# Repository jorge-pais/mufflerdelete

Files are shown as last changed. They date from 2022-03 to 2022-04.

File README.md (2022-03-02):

# Muffler Delete
Guitar distortion/fuzz effect based on the 72' Triangle Big Muff, featuring an alternate clipping mode using LEDs and a seperate boost circuit.

## Circuit Schematic
surface11700

## 3D Board View
muffboard
muffboard

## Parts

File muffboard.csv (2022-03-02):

Source: | /home/jorge/repos/muffboard/muffboard.kicad_sch
Date: | qua 02 mar 2022 12:33:31
Tool: | Eeschema (6.0.2)
Generator: | /usr/share/kicad/plugins/bom_csv_grouped_by_value.py
Component Count: | 65
Individual Components:
Item | Qty | Reference(s) | Value | LibPart | Footprint | Datasheet
 |  | C1 | 100n | Device:C | Capacitor_THT:C_Rect_L7.2mm_W2.5mm_P5.00mm_FKS2_FKP2_MKS2_MKP2 | ~
 |  | C2 | 100u | Device:C_Polarized | Capacitor_THT:CP_Radial_D6.3mm_P2.50mm | ~
 |  | C3 | 470p | Device:C | Capacitor_THT:C_Rect_L7.2mm_W2.5mm_P5.00mm_FKS2_FKP2_MKS2_MKP2 | ~
 |  | C4 | 100n | Device:C | Capacitor_THT:C_Rect_L7.2mm_W2.5mm_P5.00mm_FKS2_FKP2_MKS2_MKP2 | ~
 |  | C5 | 100n | Device:C | Capacitor_THT:C_Rect_L7.2mm_W2.5mm_P5.00mm_FKS2_FKP2_MKS2_MKP2 | ~
 |  | C6 | 47n | Device:C | Capacitor_THT:C_Rect_L7.2mm_W2.5mm_P5.00mm_FKS2_FKP2_MKS2_MKP2 | ~
 |  | C7 | 470p | Device:C | Capacitor_THT:C_Rect_L7.2mm_W2.5mm_P5.00mm_FKS2_FKP2_MKS2_MKP2 | ~
 |  | C8 | 100n | Device:C | Capacitor_THT:C_Rect_L7.2mm_W2.5mm_P5.00mm_FKS2_FKP2_MKS2_MKP2 | ~
 |  | C9 | 47n | Device:C | Capacitor_THT:C_Rect_L7.2mm_W2.5mm_P5.00mm_FKS2_FKP2_MKS2_MKP2 | ~
 |  | C10 | 470p | Device:C | Capacitor_THT:C_Rect_L7.2mm_W2.5mm_P5.00mm_FKS2_FKP2_MKS2_MKP2 | ~
 |  | C11 | 4n | Device:C | Capacitor_THT:C_Rect_L7.2mm_W2.5mm_P5.00mm_FKS2_FKP2_MKS2_MKP2 | ~
 |  | C12 | 10n | Device:C | Capacitor_THT:C_Rect_L7.2mm_W2.5mm_P5.00mm_FKS2_FKP2_MKS2_MKP2 | ~
 |  | C13 | 100n | Device:C | Capacitor_THT:C_Rect_L7.2mm_W2.5mm_P5.00mm_FKS2_FKP2_MKS2_MKP2 | ~
 |  | C14 | 100n | Device:C | Capacitor_THT:C_Rect_L7.2mm_W2.5mm_P5.00mm_FKS2_FKP2_MKS2_MKP2 | ~
 |  | C15 | 100n | Device:C | Capacitor_THT:C_Rect_L7.2mm_W2.5mm_P5.00mm_FKS2_FKP2_MKS2_MKP2 | ~
 |  | C16 | 100n | Device:C | Capacitor_THT:C_Rect_L7.2mm_W2.5mm_P5.00mm_FKS2_FKP2_MKS2_MKP2 | ~
 |  | D1 | 1N4007 | Diode:1N4007 | Diode_THT:D_DO-41_SOD81_P10.16mm_Horizontal | http://www.vishay.com/docs/88503/1n4001.pdf
 |  | D2 | 1N4148 | Diode:1N4148 | Diode_THT:D_DO-35_SOD27_P7.62mm_Horizontal | https://assets.nexperia.com/documents/data-sheet/1N4148_1N4448.pdf
 |  | D3 | 1N4148 | Diode:1N4148 | Diode_THT:D_DO-35_SOD27_P7.62mm_Horizontal | https://assets.nexperia.com/documents/data-sheet/1N4148_1N4448.pdf
 |  | D4 | RED | Device:LED | LED_THT:LED_D3.0mm | ~
 |  | D5 | RED | Device:LED | LED_THT:LED_D3.0mm | ~
 |  | D6 | 1N4148 | Diode:1N4148 | Diode_THT:D_DO-35_SOD27_P7.62mm_Horizontal | https://assets.nexperia.com/documents/data-sheet/1N4148_1N4448.pdf
 |  | D7 | 1N4148 | Diode:1N4148 | Diode_THT:D_DO-35_SOD27_P7.62mm_Horizontal | https://assets.nexperia.com/documents/data-sheet/1N4148_1N4448.pdf
 |  | D8 | RED | Device:LED | LED_THT:LED_D3.0mm | ~
 |  | D9 | RED | Device:LED | LED_THT:LED_D3.0mm | ~
 |  | J1 | Conn_01x02 | Connector_Generic:Conn_01x02 | Connector_PinHeader_2.54mm:PinHeader_1x02_P2.54mm_Vertical | ~
 |  | J2 | Conn_01x03 | Connector_Generic:Conn_01x03 | Connector_PinHeader_2.54mm:PinHeader_1x03_P2.54mm_Vertical | ~
 |  | J3 | Conn_01x03 | Connector_Generic:Conn_01x03 | Connector_PinHeader_2.54mm:PinHeader_1x03_P2.54mm_Vertical | ~
 |  | Q1 | BC547 | Transistor_BJT:BC547 | Package_TO_SOT_THT:TO-92_Inline_Wide | https://www.onsemi.com/pub/Collateral/BC550-D.pdf
 |  | Q2 | BC547 | Transistor_BJT:BC547 | Package_TO_SOT_THT:TO-92_Inline_Wide | https://www.onsemi.com/pub/Collateral/BC550-D.pdf
 |  | Q3 | BC547 | Transistor_BJT:BC547 | Package_TO_SOT_THT:TO-92_Inline_Wide | https://www.onsemi.com/pub/Collateral/BC550-D.pdf
 |  | Q4 | BC547 | Transistor_BJT:BC547 | Package_TO_SOT_THT:TO-92_Inline_Wide | https://www.onsemi.com/pub/Collateral/BC550-D.pdf
 |  | Q5 | BC547 | Transistor_BJT:BC547 | Package_TO_SOT_THT:TO-92_Inline_Wide | https://www.onsemi.com/pub/Collateral/BC550-D.pdf
 |  | R1 | 1M | Device:R | Resistor_THT:R_Axial_DIN0207_L6.3mm_D2.5mm_P7.62mm_Horizontal | ~
 |  | R2 | 33k | Device:R | Resistor_THT:R_Axial_DIN0207_L6.3mm_D2.5mm_P7.62mm_Horizontal | ~
 |  | R3 | 100k | Device:R | Resistor_THT:R_Axial_DIN0207_L6.3mm_D2.5mm_P7.62mm_Horizontal | ~
 |  | R4 | 470k | Device:R | Resistor_THT:R_Axial_DIN0207_L6.3mm_D2.5mm_P7.62mm_Horizontal | ~
 |  | R5 | 15k | Device:R | Resistor_THT:R_Axial_DIN0207_L6.3mm_D2.5mm_P7.62mm_Horizontal | ~
 |  | R6 | 150 | Device:R | Resistor_THT:R_Axial_DIN0207_L6.3mm_D2.5mm_P7.62mm_Horizontal | ~
 |  | R7 | 1k | Device:R | Resistor_THT:R_Axial_DIN0207_L6.3mm_D2.5mm_P7.62mm_Horizontal | ~
 |  | R8 | 8.2k | Device:R | Resistor_THT:R_Axial_DIN0207_L6.3mm_D2.5mm_P7.62mm_Horizontal | ~
 |  | R9 | 100k | Device:R | Resistor_THT:R_Axial_DIN0207_L6.3mm_D2.5mm_P7.62mm_Horizontal | ~
 |  | R10 | 470k | Device:R | Resistor_THT:R_Axial_DIN0207_L6.3mm_D2.5mm_P7.62mm_Horizontal | ~
 |  | R11 | 12k | Device:R | Resistor_THT:R_Axial_DIN0207_L6.3mm_D2.5mm_P7.62mm_Horizontal | ~
 |  | R12 | 150 | Device:R | Resistor_THT:R_Axial_DIN0207_L6.3mm_D2.5mm_P7.62mm_Horizontal | ~
 |  | R13 | 8.2k | Device:R | Resistor_THT:R_Axial_DIN0207_L6.3mm_D2.5mm_P7.62mm_Horizontal | ~
 |  | R14 | 100k | Device:R | Resistor_THT:R_Axial_DIN0207_L6.3mm_D2.5mm_P7.62mm_Horizontal | ~
 |  | R15 | 470k | Device:R | Resistor_THT:R_Axial_DIN0207_L6.3mm_D2.5mm_P7.62mm_Horizontal | ~
 |  | R16 | 12k | Device:R | Resistor_THT:R_Axial_DIN0207_L6.3mm_D2.5mm_P7.62mm_Horizontal | ~
 |  | R17 | 150 | Device:R | Resistor_THT:R_Axial_DIN0207_L6.3mm_D2.5mm_P7.62mm_Horizontal | ~
 |  | R18 | 33k | Device:R | Resistor_THT:R_Axial_DIN0207_L6.3mm_D2.5mm_P7.62mm_Horizontal | ~
 |  | R19 | 33k | Device:R | Resistor_THT:R_Axial_DIN0207_L6.3mm_D2.5mm_P7.62mm_Horizontal | ~
 |  | R20 | 470k | Device:R | Resistor_THT:R_Axial_DIN0207_L6.3mm_D2.5mm_P7.62mm_Horizontal | ~
 |  | R21 | 47k | Device:R | Resistor_THT:R_Axial_DIN0207_L6.3mm_D2.5mm_P7.62mm_Horizontal | ~
 |  | R22 | 10k | Device:R | Resistor_THT:R_Axial_DIN0207_L6.3mm_D2.5mm_P7.62mm_Horizontal | ~
 |  | R23 | 390 | Device:R | Resistor_THT:R_Axial_DIN0207_L6.3mm_D2.5mm_P7.62mm_Horizontal | ~
 |  | R24 | 470k | Device:R | Resistor_THT:R_Axial_DIN0207_L6.3mm_D2.5mm_P7.62mm_Horizontal | ~
 |  | R25 | 100k | Device:R | Resistor_THT:R_Axial_DIN0207_L6.3mm_D2.5mm_P7.62mm_Horizontal | ~
 |  | R26 | 12k | Device:R | Resistor_THT:R_Axial_DIN0207_L6.3mm_D2.5mm_P7.62mm_Horizontal | ~
 |  | R27 | 2.7k | Device:R | Resistor_THT:R_Axial_DIN0207_L6.3mm_D2.5mm_P7.62mm_Horizontal | ~
 |  | RV1 | 100k | Device:R_Potentiometer | Potentiometer_THT:Potentiometer_Omeg_PC16BU_Vertical | ~
 |  | RV2 | 100k | Device:R_Potentiometer | Potentiometer_THT:Potentiometer_Omeg_PC16BU_Vertical | ~
 |  | RV3 | 100k | Device:R_Potentiometer | Potentiometer_THT:Potentiometer_Omeg_PC16BU_Vertical | ~
 |  | RV4 | 100k | Device:R_Potentiometer | Potentiometer_THT:Potentiometer_Omeg_PC16BU_Vertical | ~
 |  | SW1 | SW_DPDT_x2 | Switch:SW_DPDT_x2 | Button_Switch_THT:SW_E-Switch_EG1271_DPDT | ~
Collated Components:
Item | Qty | Reference(s) | Value | LibPart | Footprint | Datasheet
1 | 8 | C1, C4, C5, C8, C13, C14, C15, C16 | 100n | Device:C | Capacitor_THT:C_Rect_L7.2mm_W2.5mm_P5.00mm_FKS2_FKP2_MKS2_MKP2 | ~
2 | 1 | C2 | 100u | Device:C_Polarized | Capacitor_THT:CP_Radial_D6.3mm_P2.50mm | ~
3 | 3 | C3, C7, C10 | 470p | Device:C | Capacitor_THT:C_Rect_L7.2mm_W2.5mm_P5.00mm_FKS2_FKP2_MKS2_MKP2 | ~
4 | 2 | C6, C9 | 47n | Device:C | Capacitor_THT:C_Rect_L7.2mm_W2.5mm_P5.00mm_FKS2_FKP2_MKS2_MKP2 | ~
5 | 1 | C11 | 4n | Device:C | Capacitor_THT:C_Rect_L7.2mm_W2.5mm_P5.00mm_FKS2_FKP2_MKS2_MKP2 | ~
6 | 1 | C12 | 10n | Device:C | Capacitor_THT:C_Rect_L7.2mm_W2.5mm_P5.00mm_FKS2_FKP2_MKS2_MKP2 | ~
7 | 1 | D1 | 1N4007 | Diode:1N4007 | Diode_THT:D_DO-41_SOD81_P10.16mm_Horizontal | http://www.vishay.com/docs/88503/1n4001.pdf
8 | 4 | D2, D3, D6, D7 | 1N4148 | Diode:1N4148 | Diode_THT:D_DO-35_SOD27_P7.62mm_Horizontal | https://assets.nexperia.com/documents/data-sheet/1N4148_1N4448.pdf
9 | 4 | D4, D5, D8, D9 | RED | Device:LED | LED_THT:LED_D3.0mm | ~
10 | 1 | J1 | Conn_01x02 | Connector_Generic:Conn_01x02 | Connector_PinHeader_2.54mm:PinHeader_1x02_P2.54mm_Vertical | ~
11 | 2 | J2, J3 | Conn_01x03 | Connector_Generic:Conn_01x03 | Connector_PinHeader_2.54mm:PinHeader_1x03_P2.54mm_Vertical | ~
12 | 5 | Q1, Q2, Q3, Q4, Q5 | BC547 | Transistor_BJT:BC547 | Package_TO_SOT_THT:TO-92_Inline_Wide | https://www.onsemi.com/pub/Collateral/BC550-D.pdf
13 | 1 | R1 | 1M | Device:R | Resistor_THT:R_Axial_DIN0207_L6.3mm_D2.5mm_P7.62mm_Horizontal | ~
14 | 3 | R2, R18, R19 | 33k | Device:R | Resistor_THT:R_Axial_DIN0207_L6.3mm_D2.5mm_P7.62mm_Horizontal | ~
15 | 4 | R3, R9, R14, R25 | 100k | Device:R | Resistor_THT:R_Axial_DIN0207_L6.3mm_D2.5mm_P7.62mm_Horizontal | ~
16 | 5 | R4, R10, R15, R20, R24 | 470k | Device:R | Resistor_THT:R_Axial_DIN0207_L6.3mm_D2.5mm_P7.62mm_Horizontal | ~
17 | 1 | R5 | 15k | Device:R | Resistor_THT:R_Axial_DIN0207_L6.3mm_D2.5mm_P7.62mm_Horizontal | ~
18 | 3 | R6, R12, R17 | 150 | Device:R | Resistor_THT:R_Axial_DIN0207_L6.3mm_D2.5mm_P7.62mm_Horizontal | ~
19 | 1 | R7 | 1k | Device:R | Resistor_THT:R_Axial_DIN0207_L6.3mm_D2.5mm_P7.62mm_Horizontal | ~
20 | 2 | R8, R13 | 8.2k | Device:R | Resistor_THT:R_Axial_DIN0207_L6.3mm_D2.5mm_P7.62mm_Horizontal | ~
21 | 3 | R11, R16, R26 | 12k | Device:R | Resistor_THT:R_Axial_DIN0207_L6.3mm_D2.5mm_P7.62mm_Horizontal | ~
22 | 1 | R21 | 47k | Device:R | Resistor_THT:R_Axial_DIN0207_L6.3mm_D2.5mm_P7.62mm_Horizontal | ~
23 | 1 | R22 | 10k | Device:R | Resistor_THT:R_Axial_DIN0207_L6.3mm_D2.5mm_P7.62mm_Horizontal | ~
24 | 1 | R23 | 390 | Device:R | Resistor_THT:R_Axial_DIN0207_L6.3mm_D2.5mm_P7.62mm_Horizontal | ~
25 | 1 | R27 | 2.7k | Device:R | Resistor_THT:R_Axial_DIN0207_L6.3mm_D2.5mm_P7.62mm_Horizontal | ~
26 | 4 | RV1, RV2, RV3, RV4 | 100k | Device:R_Potentiometer | Potentiometer_THT:Potentiometer_Omeg_PC16BU_Vertical | ~
27 | 1 | SW1 | SW_DPDT_x2 | Switch:SW_DPDT_x2 | Button_Switch_THT:SW_E-Switch_EG1271_DPDT | ~

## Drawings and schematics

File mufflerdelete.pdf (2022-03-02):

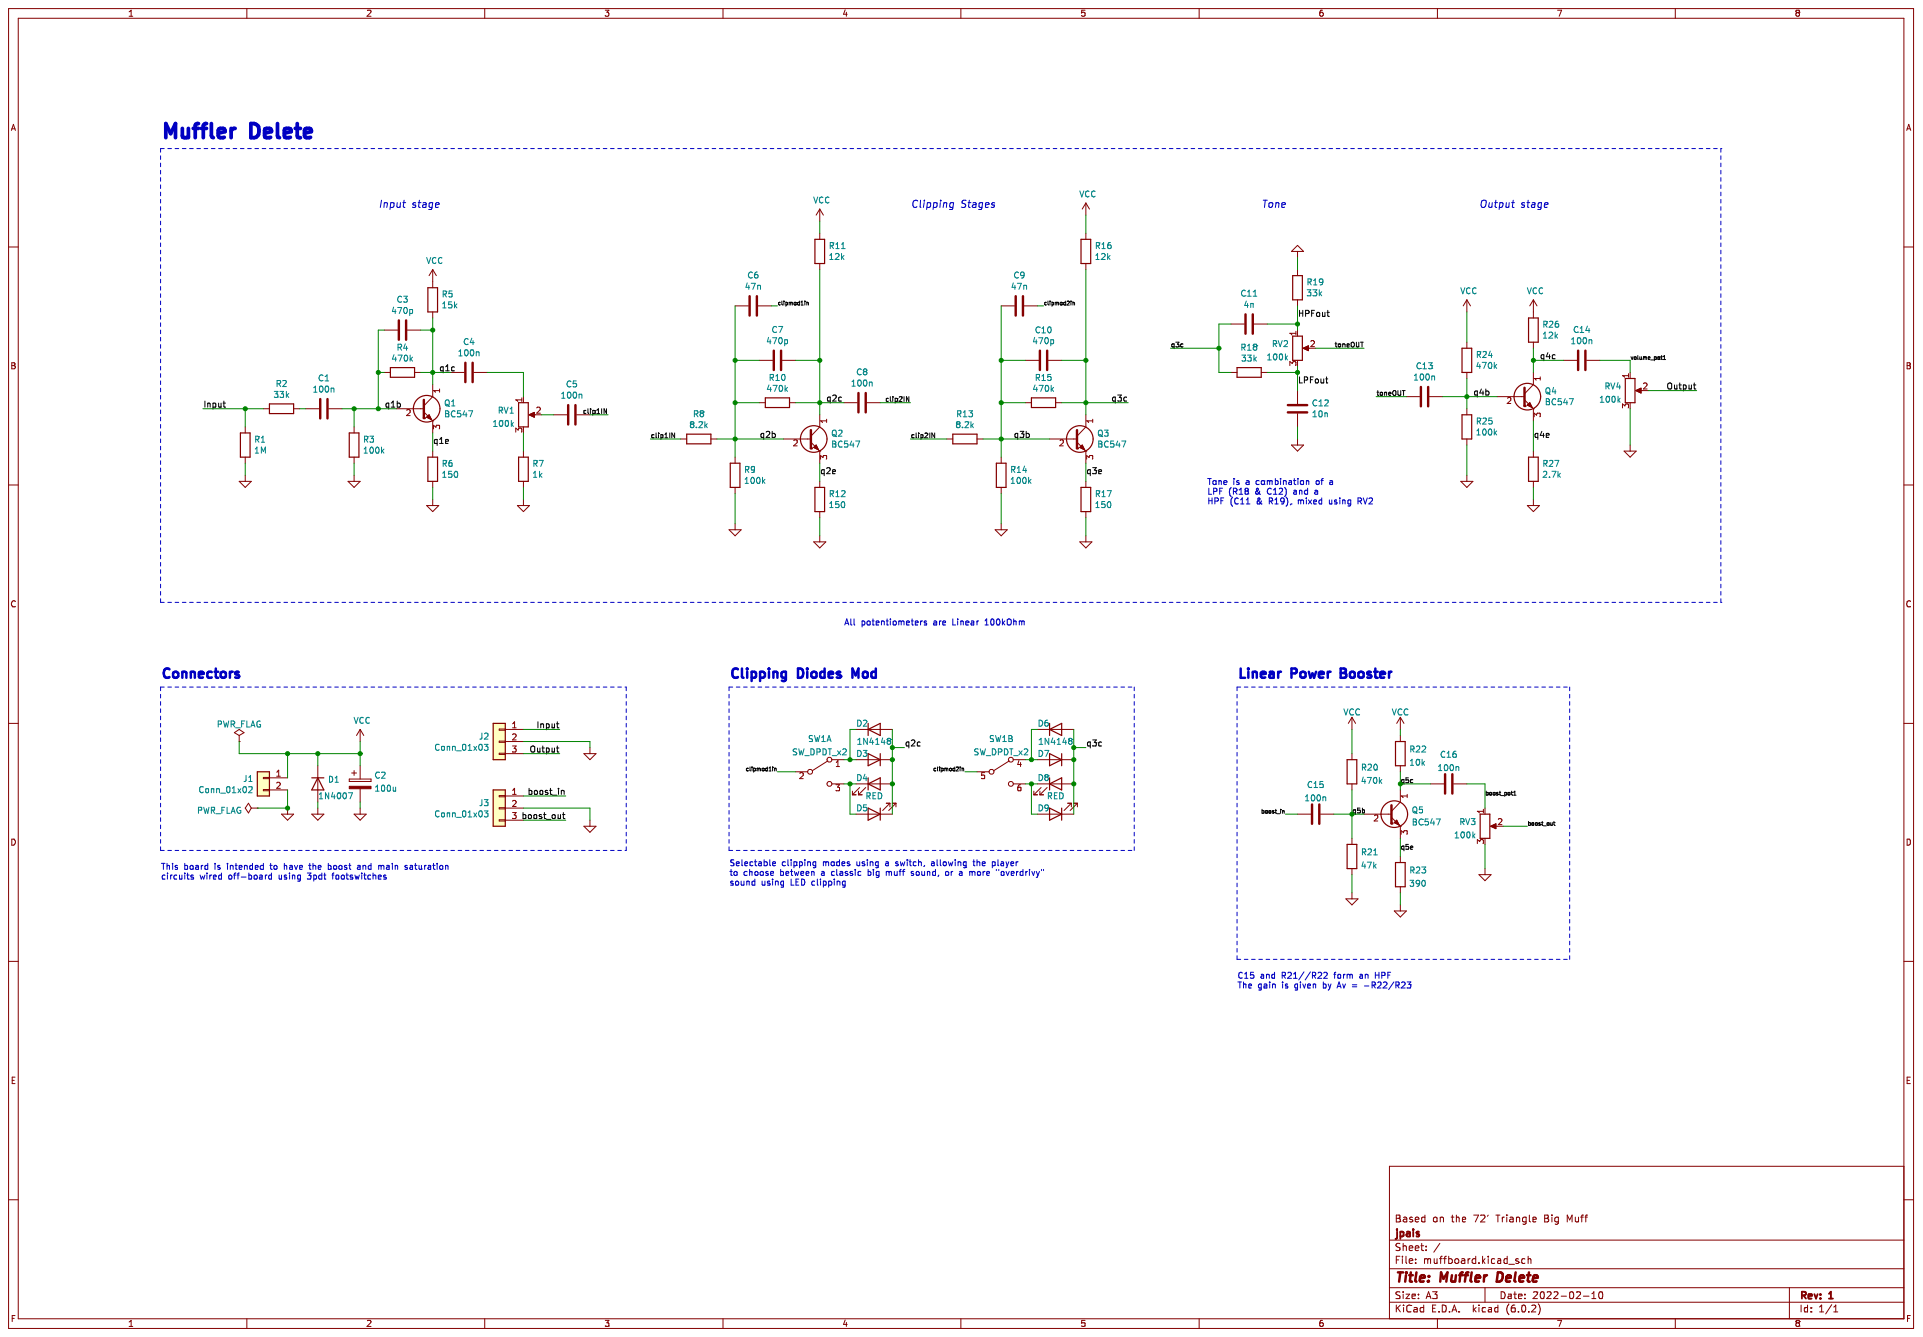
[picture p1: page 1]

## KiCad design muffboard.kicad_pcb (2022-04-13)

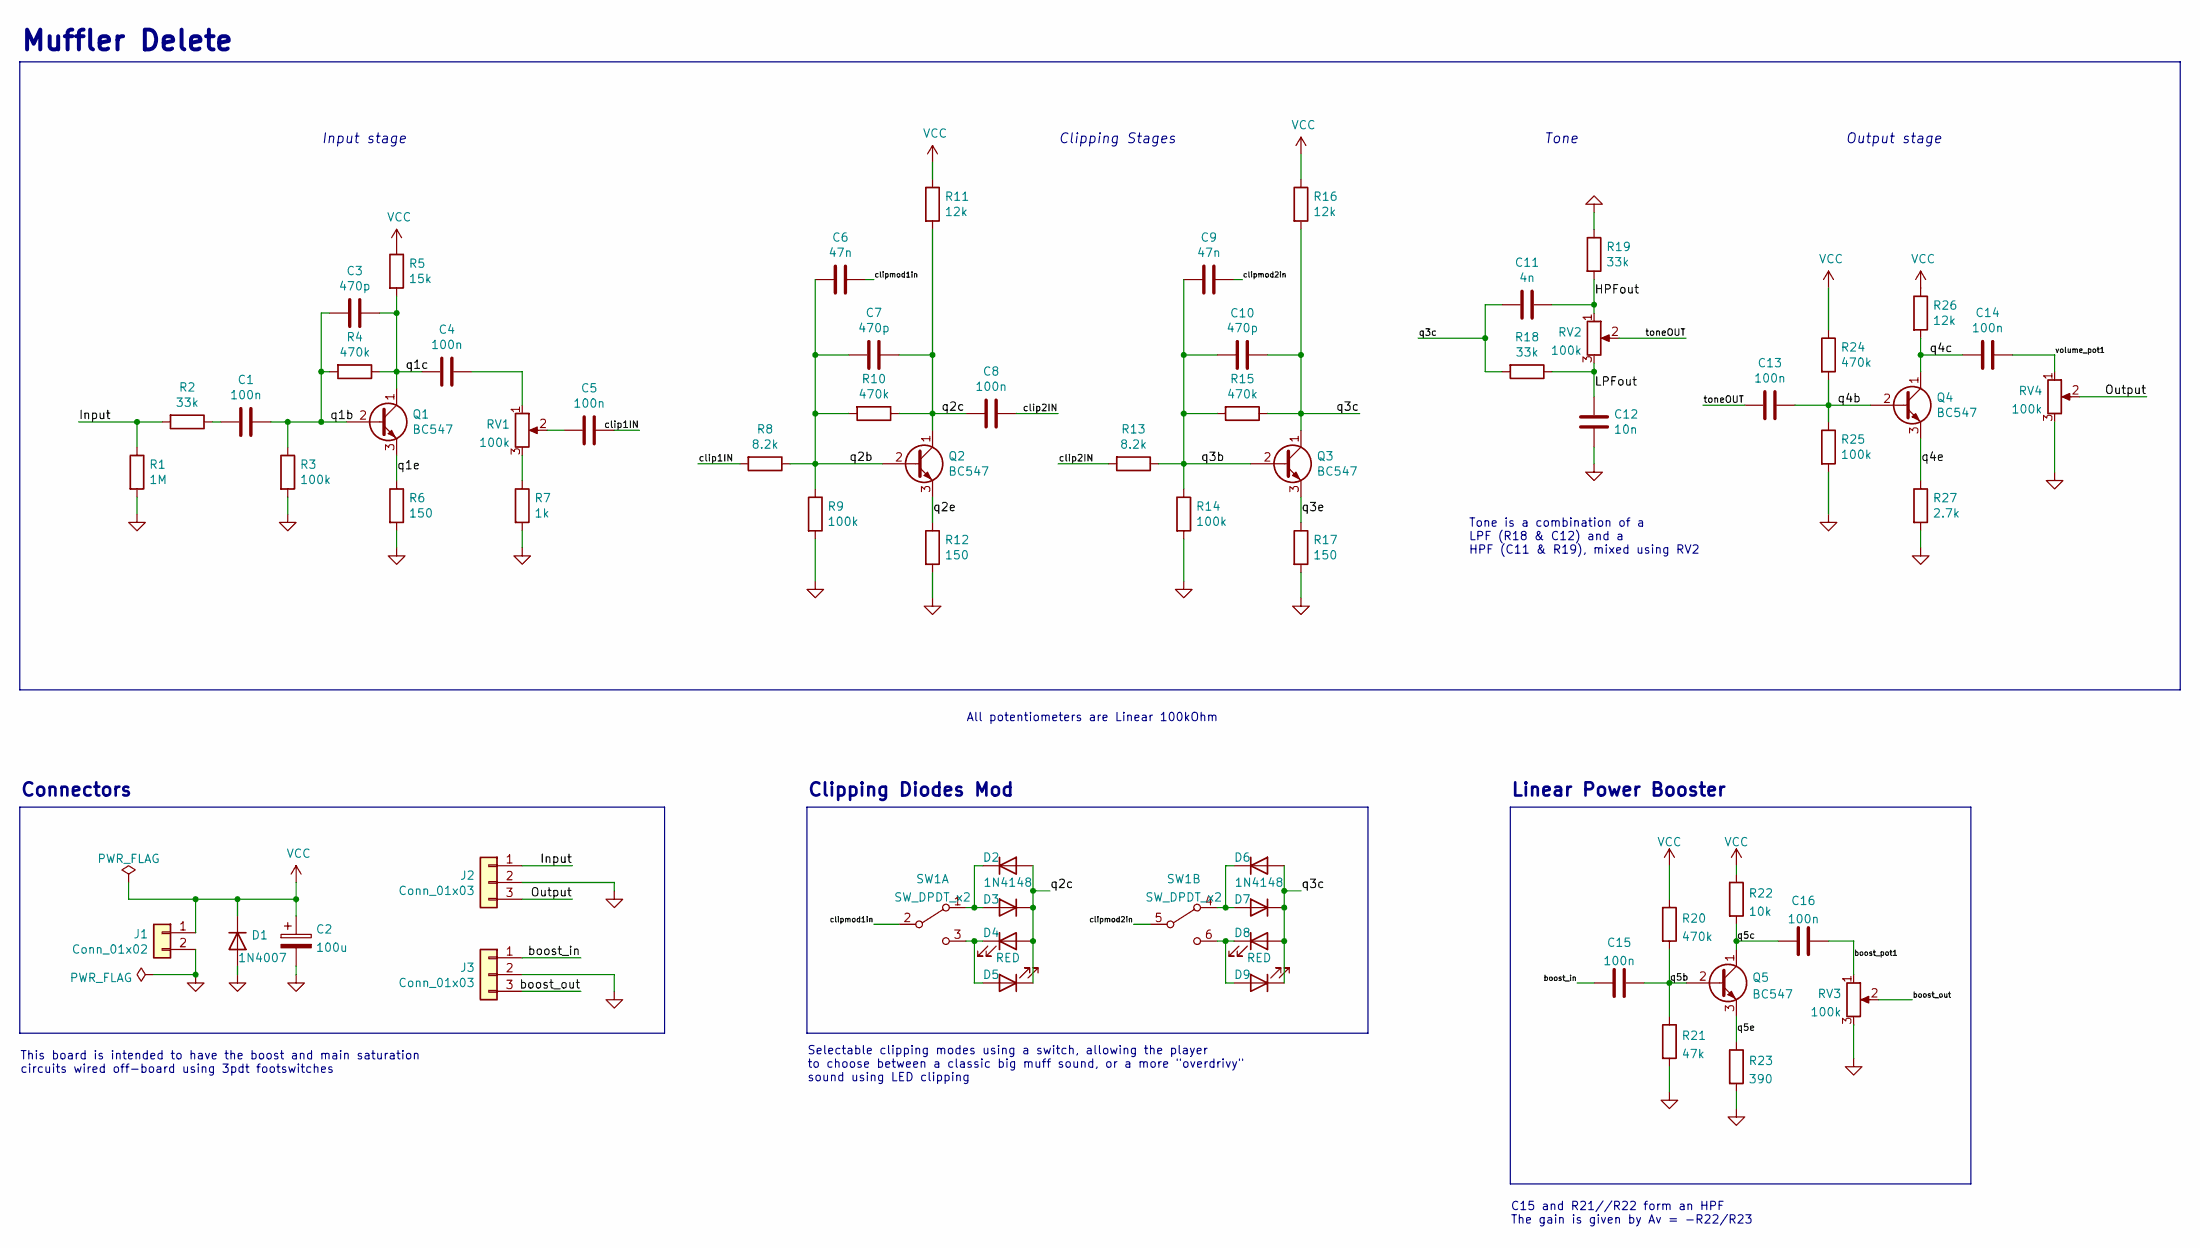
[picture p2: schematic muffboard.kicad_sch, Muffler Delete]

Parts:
C1, C4, C5, C8, C13, C14, C15, C16: 100n; C_Rect_L7.2mm_W2.5mm_P5.00mm_FKS2_FKP2_MKS2_MKP2
C2: 100u; CP_Radial_D6.3mm_P2.50mm
C3, C7, C10: 470p; C_Rect_L7.2mm_W2.5mm_P5.00mm_FKS2_FKP2_MKS2_MKP2
C6, C9: 47n; C_Rect_L7.2mm_W2.5mm_P5.00mm_FKS2_FKP2_MKS2_MKP2
C11: 4n; C_Rect_L7.2mm_W2.5mm_P5.00mm_FKS2_FKP2_MKS2_MKP2
C12: 10n; C_Rect_L7.2mm_W2.5mm_P5.00mm_FKS2_FKP2_MKS2_MKP2
D1: 1N4007; D_DO-41_SOD81_P10.16mm_Horizontal
D2, D3, D6, D7: 1N4148; D_DO-35_SOD27_P7.62mm_Horizontal
D4, D5, D8, D9: RED; LED_D3.0mm
J1: Conn_01x02; PinHeader_1x02_P2.54mm_Vertical
J2, J3: Conn_01x03; PinHeader_1x03_P2.54mm_Vertical
Q1, Q2, Q3, Q4, Q5: BC547; TO-92_Inline_Wide
R1: 1M; R_Axial_DIN0207_L6.3mm_D2.5mm_P7.62mm_Horizontal
R2, R18, R19: 33k; R_Axial_DIN0207_L6.3mm_D2.5mm_P7.62mm_Horizontal
R3, R9, R14, R25: 100k; R_Axial_DIN0207_L6.3mm_D2.5mm_P7.62mm_Horizontal
R4, R10, R15, R20, R24: 470k; R_Axial_DIN0207_L6.3mm_D2.5mm_P7.62mm_Horizontal
R5: 15k; R_Axial_DIN0207_L6.3mm_D2.5mm_P7.62mm_Horizontal
R6, R12, R17: 150; R_Axial_DIN0207_L6.3mm_D2.5mm_P7.62mm_Horizontal
R7: 1k; R_Axial_DIN0207_L6.3mm_D2.5mm_P7.62mm_Horizontal
R8, R13: 8.2k; R_Axial_DIN0207_L6.3mm_D2.5mm_P7.62mm_Horizontal
R11, R16, R26: 12k; R_Axial_DIN0207_L6.3mm_D2.5mm_P7.62mm_Horizontal
R21: 47k; R_Axial_DIN0207_L6.3mm_D2.5mm_P7.62mm_Horizontal
R22: 10k; R_Axial_DIN0207_L6.3mm_D2.5mm_P7.62mm_Horizontal
R23: 390; R_Axial_DIN0207_L6.3mm_D2.5mm_P7.62mm_Horizontal
R27: 2.7k; R_Axial_DIN0207_L6.3mm_D2.5mm_P7.62mm_Horizontal
RV1, RV2, RV3, RV4: 100k; Potentiometer_Omeg_PC16BU_Vertical
SW1: SW_DPDT_x2; SW_E-Switch_EG1271_DPDT

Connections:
/HPFout: C11.1, R19.2, RV2.1
/Input: J2.1, R1.1, R2.2
/LPFout: C12.1, R18.1, RV2.3
/Output: J2.3, RV4.2
/boost_in: C15.1, J3.1
/boost_out: J3.3, RV3.2
/boost_pot1: C16.2, RV3.1
/clip1IN: C5.1, R8.2
/clip2IN: C8.1, R13.2
/clipmod1in: C6.1, SW1.2 (B)
/clipmod2in: C9.1, SW1.5 (B)
/q1b: C1.1, C3.2, Q1.2 (B), R3.1, R4.2
/q1c: C3.1, C4.2, Q1.1 (C), R4.1, R5.2
/q1e: Q1.3 (E), R6.1
/q2b: C6.2, C7.2, Q2.2 (B), R8.1, R9.1, R10.2
/q2c: C7.1, C8.2, D2.2 (A), D3.1 (K), D4.2 (A), D5.1 (K), Q2.1 (C), R10.1, R11.2
/q2e: Q2.3 (E), R12.1
/q3b: C9.2, C10.2, Q3.2 (B), R13.1, R14.1, R15.2
/q3c: C10.1, C11.2, D6.2 (A), D7.1 (K), D8.2 (A), D9.1 (K), Q3.1 (C), R15.1, R16.2, R18.2
/q3e: Q3.3 (E), R17.1
/q4b: C13.2, Q4.2 (B), R24.2, R25.1
/q4c: C14.2, Q4.1 (C), R26.2
/q4e: Q4.3 (E), R27.1
/q5b: C15.2, Q5.2 (B), R20.2, R21.1
/q5c: C16.1, Q5.1 (C), R22.2
/q5e: Q5.3 (E), R23.1
/toneOUT: C13.1, RV2.2
/volume_pot1: C14.1, RV4.1
GND: C2.2, C12.2, D1.2 (A), J1.2, J2.2, J3.2, R1.2, R3.2, R6.2, R7.2, R9.2, R12.2, R14.2, R17.2, R19.1, R21.2, R23.2, R25.2, R27.2, RV3.3, RV4.3
unnamed: C1.2, R2.1
unnamed: C4.1, RV1.1
unnamed: C5.2, RV1.2
unnamed: D2.1 (K), D3.2 (A), SW1.1 (A)
unnamed: D4.1 (K), D5.2 (A), SW1.3 (C)
unnamed: D6.1 (K), D7.2 (A), SW1.4 (A)
unnamed: D8.1 (K), D9.2 (A), SW1.6 (C)
unnamed: R7.1, RV1.3
VCC: C2.1, D1.1 (K), J1.1, R5.1, R11.1, R16.1, R20.1, R22.1, R24.1, R26.1

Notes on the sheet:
Connectors
Muffler Delete
Selectable clipping modes using a switch, allowing the player to choose between a classic big muff sound, or a more "overdrivy" sound using LED clipping
Clipping Stages
Input stage
Output stage
Clipping Diodes Mod
Tone
This board is intended to have the boost and main saturation circuits wired off-board using 3pdt footswitches
All potentiometers are Linear 100kOhm
Tone is a combination of a LPF (R18 & C12) and a HPF (C11 & R19), mixed using RV2
Linear Power Booster
C15 and R21//R22 form an HPF The gain is given by Av = -R22/R23

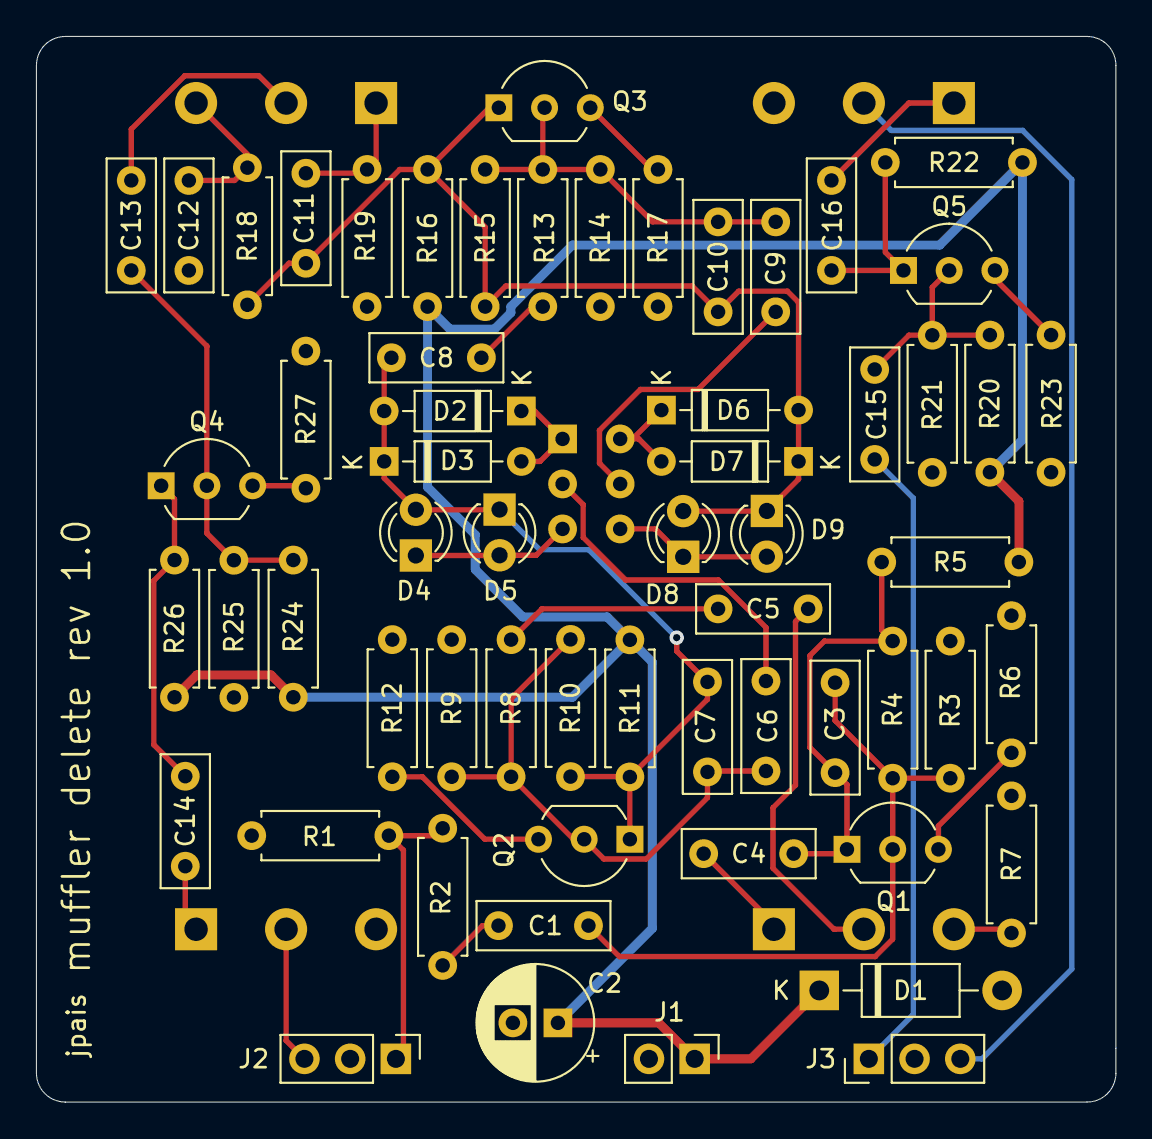
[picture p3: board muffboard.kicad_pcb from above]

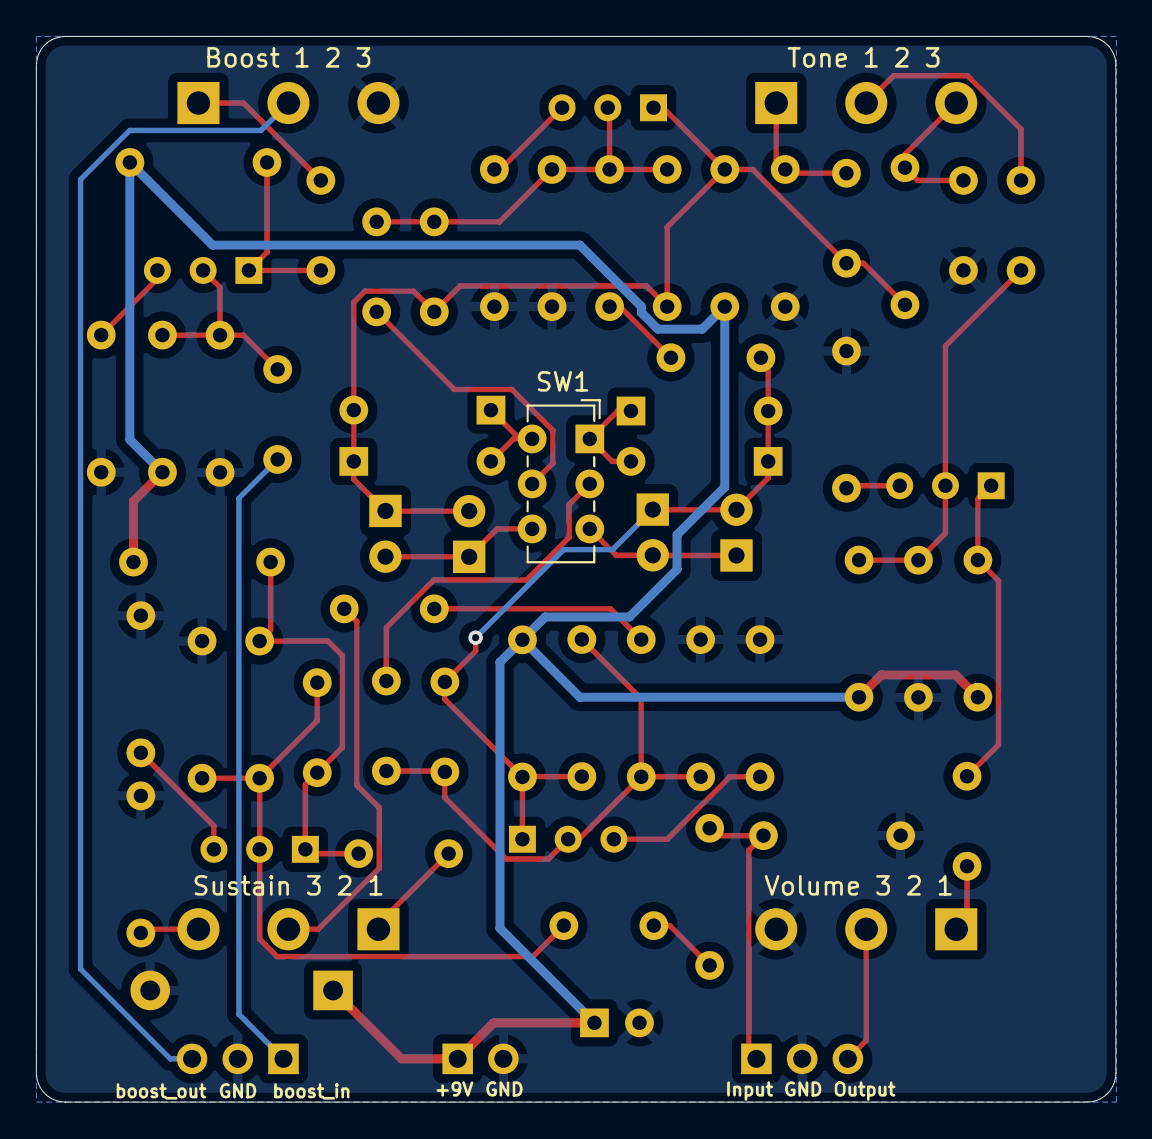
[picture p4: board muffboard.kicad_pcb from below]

Board: 2 copper layers, 60.0 x 59.2 mm, 65 parts (5 on the bottom side), 38 nets.

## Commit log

2022-03-01 removed useless files
    [muffboard_diodemod.kicad_sch]
2022-03-01 initial component placing on pcb
    [muffboard.kicad_pcb, muffboard.kicad_sch]
2022-03-01 finished board (de estoura)
    [muffboard.kicad_pcb, muffboard.kicad_sch]
2022-03-02 added BOM and schematic pdf
    [muffboard.csv]
2022-03-02 rev 1.0 board
    [muffboard.kicad_pcb]
2022-03-02 Edit pcb
2022-04-13 Added LICENSE.md
    [muffboard.kicad_pcb]
